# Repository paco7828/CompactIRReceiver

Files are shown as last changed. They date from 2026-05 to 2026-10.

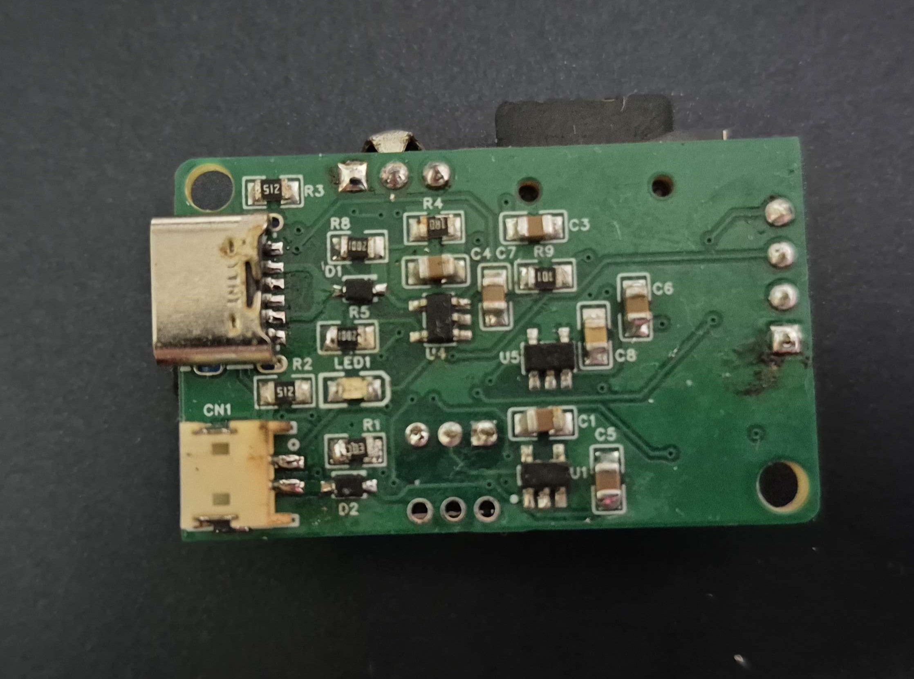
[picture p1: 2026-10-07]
showcase/pcb1.jpg

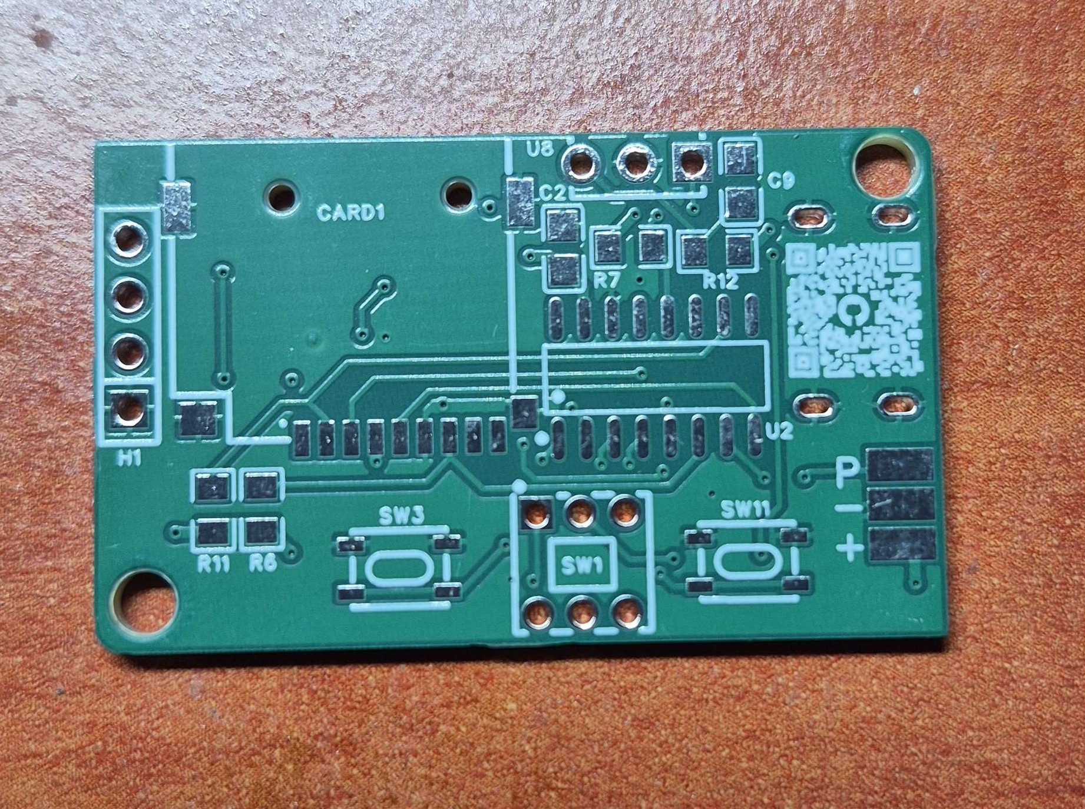
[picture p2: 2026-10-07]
showcase/pcb3.jpg

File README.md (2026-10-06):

# CompactIRReceiver

A palm-sized, battery-powered infrared (IR) signal receiver and logger based on the WCH CH32V003 RISC-V microcontroller. It decodes incoming IR signals, measures raw pulse lengths, displays the output on an I2C OLED display, and optionally logs raw timing data to a FAT32-formatted MicroSD card.

## Technical Specifications

| Component | Specification / Part Number |
| --- | --- |
| Microcontroller | WCH CH32V003A4M6 (RISC-V, 48 MHz, 2 KB RAM, 16 KB Flash) |
| IR Receiver Module | IRM-3638T (38 kHz) |
| Display | 0.91" 128x32 Monochrome I2C OLED (White) |
| Battery & Power | 300 mAh 3.7V LiPo battery |
| Charge Controller | LP4054 (USB-C charging) |
| Battery Protection | XB5352A (Overcharge, over-discharge, overcurrent protection) |
| Voltage Regulator | AP2112K-3.3 LDO (3.3V system power) |
| Power Switch | Latching push button |
| User Interface | 2x Push buttons (Confirm / Cancel) |
| Storage | MicroSD slot (Software SPI mode) |

## System Architecture & Memory Constraints

The CH32V003 has 2 KB of SRAM. To operate within these limits, the firmware shares a single 512-byte buffer (`buf[512]`):
- **UI State:** Used as the monochrome OLED display framebuffer (128x32 / 8 = 512 bytes).

MicroSD communications are handled via a lightweight, bit-banged SPI implementation with custom FAT32 root directory scanning and file writing functions.

## Operating Flow

1. **Boot:** Power on via the latching switch. The OLED displays the splash screen (`IR Receiver`).
2. **Listen:** Press **Confirm** to enter listening mode. The screen displays `Listening` with a loading animation.
   - Pressing **Confirm** or **Cancel** at any time while listening aborts the capture and returns to the boot screen.
3. **Capture:** When a signal is captured, the device displays:
   - Decoded hex value (e.g., `0x12345678`).
   - Total raw pulse count (e.g., `raw length: 32`).
   - Confirm (Check icon) and Cancel (Cross icon) indicators on screen.
4. **Save / Discard:**
   - Press **Confirm** to save the capture to the SD card.
   - Press **Cancel** to discard the capture without writing to disk.
5. **Feedback:** Shows status output (`Saved!`, `No SD card`, `Not FAT32`, `SD wr err`, or `Cancel X`) for 3 seconds before returning to the boot screen.

## SD Card Logging Format

Saved files are stored in the root directory under the 8.3 naming convention: `SIGxxxxx.TXT` (incrementing from `SIG00001.TXT` to `SIG99999.TXT`).

Format inside the text file:
```text
{HEX_VALUE};{RAW_COUNT};{{RAW_PULSE_MICROSECONDS_ARRAY}}
```

Example:
```text
A55A1234;12;{9000,4500,560,1690,560,560,560,1690,560,560,560,560}
```

## Toolchain & Compilation

Built using **MounRiver Studio II** targeting the CH32V003 platform.

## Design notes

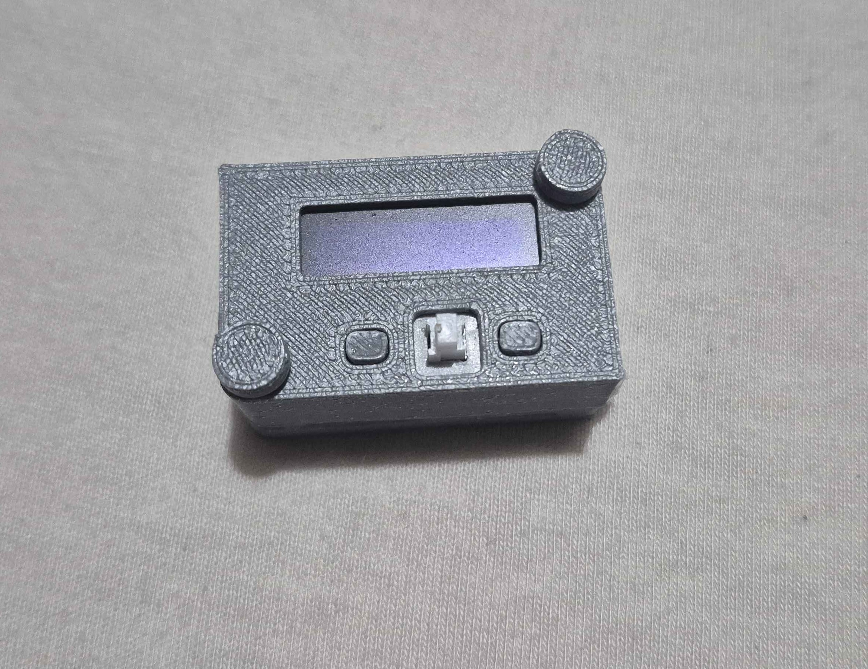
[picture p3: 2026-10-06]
showcase/compactirreceiver1.jpg

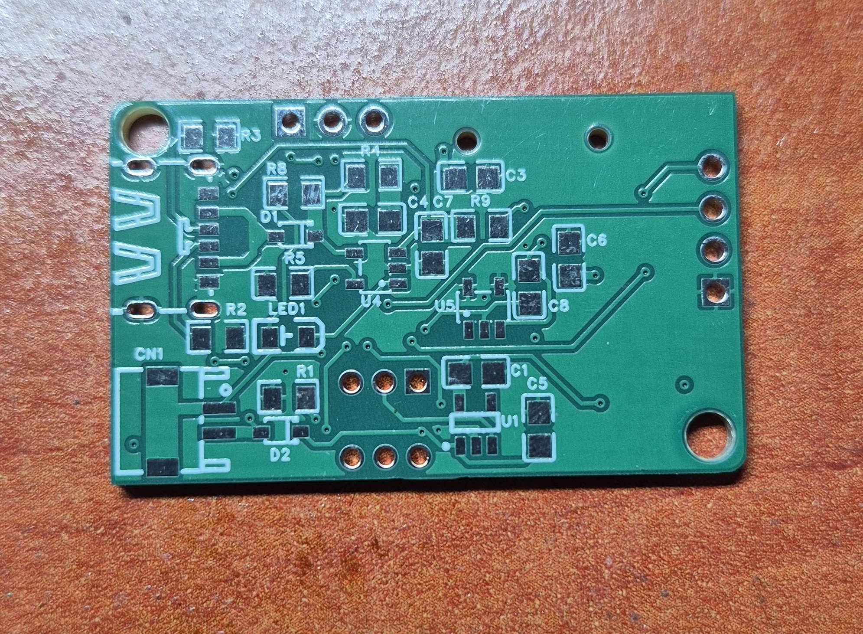
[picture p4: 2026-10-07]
showcase/pcb4.jpg

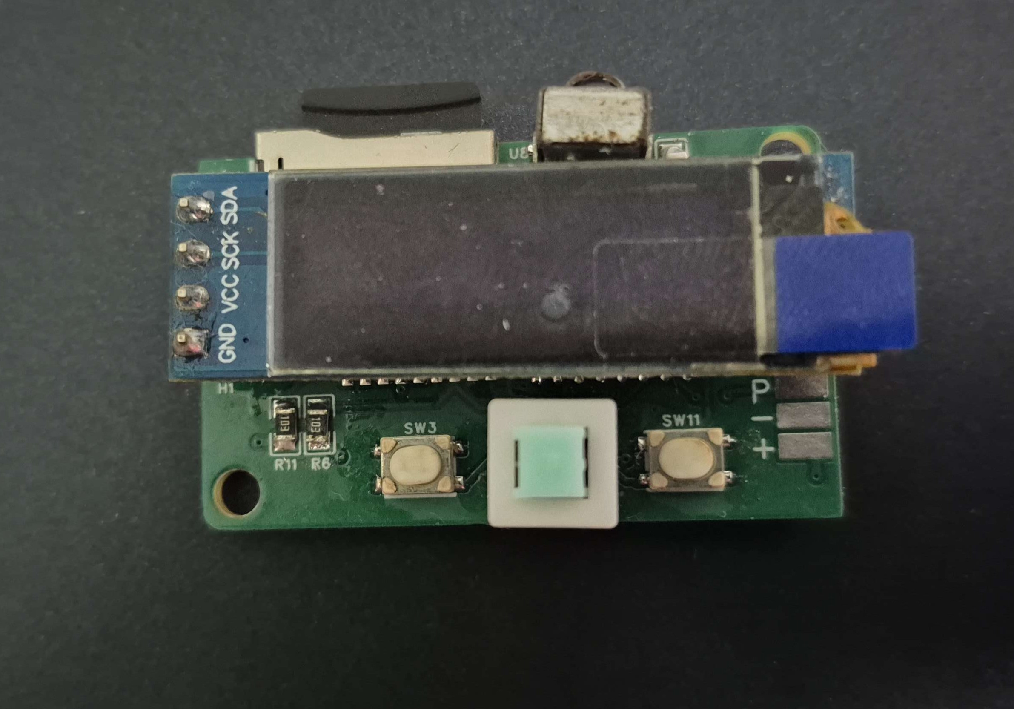
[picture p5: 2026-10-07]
showcase/pcb2.jpg

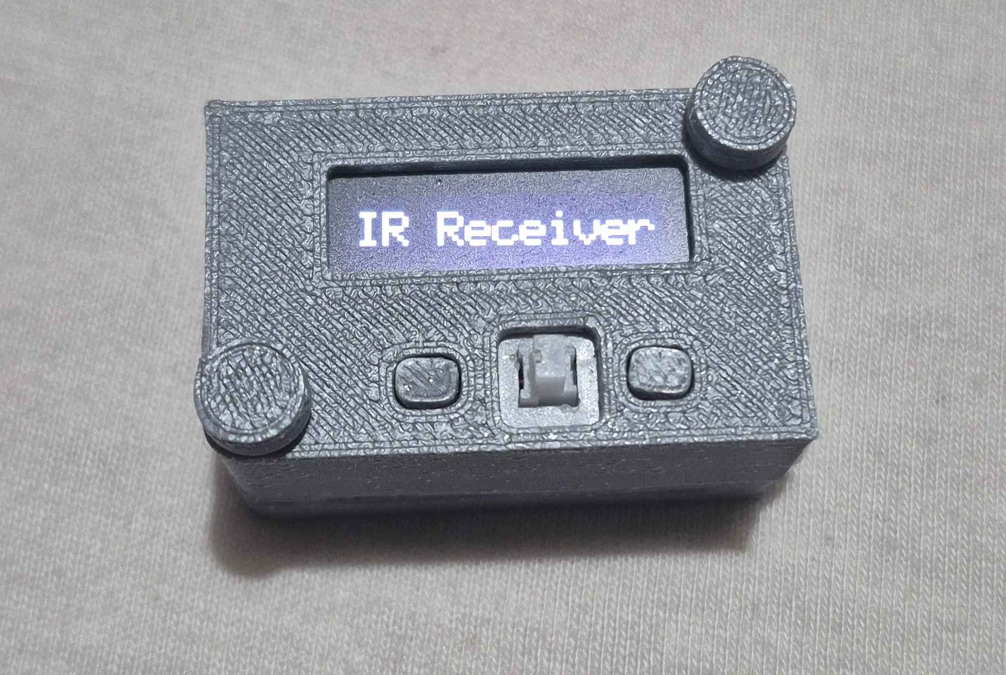
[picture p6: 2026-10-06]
showcase/compactirreceiver2.jpg

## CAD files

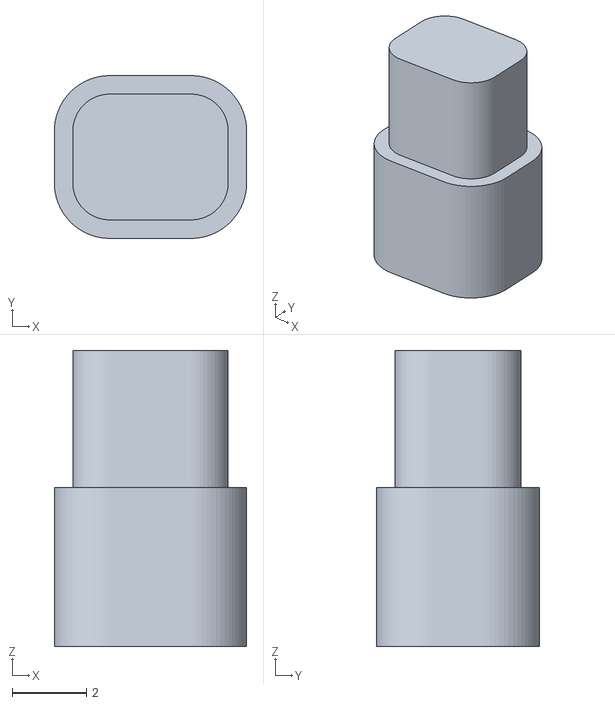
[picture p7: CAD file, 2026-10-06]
3d-files/CompactIRReceiver-button-presser.stl
5.20 x 4.40 x 8.00

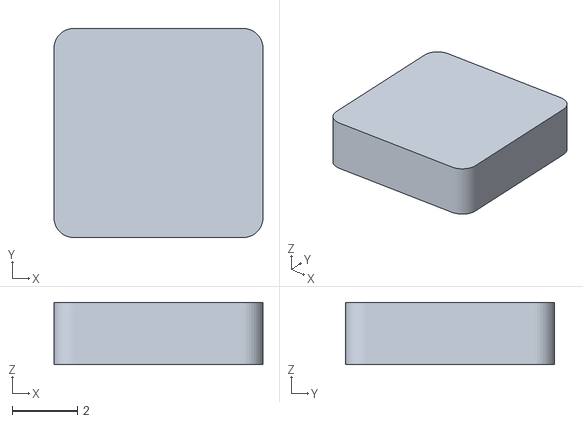
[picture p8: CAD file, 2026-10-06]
3d-files/CompactIRReceiver-power-presser.stl
6.40 x 6.40 x 1.90

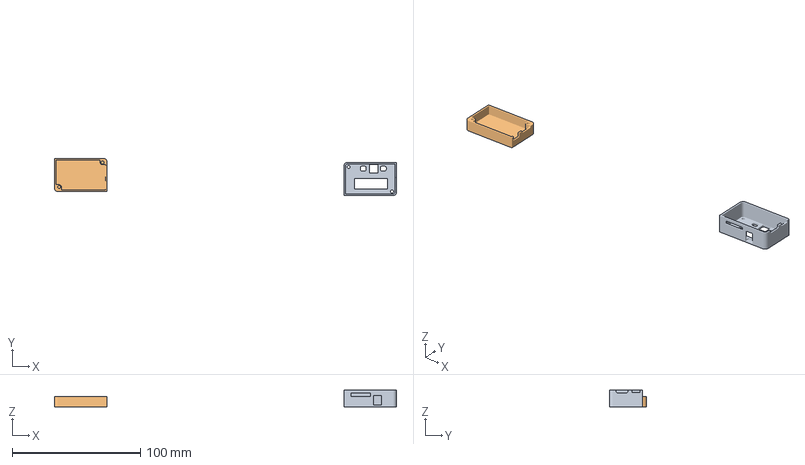
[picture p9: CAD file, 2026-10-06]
3d-files/CompactIRReceiver-box.3mf
266.2 x 29.2 x 13.0 mm
Body1.stl_A
Body1.stl_B

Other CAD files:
3d-files/CompactIRReceiver-box.stl

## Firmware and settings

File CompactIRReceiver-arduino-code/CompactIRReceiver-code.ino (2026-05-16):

#include <IRrecv.h>
#include <IRutils.h>
#include <Wire.h>
#include <Adafruit_GFX.h>
#include <Adafruit_SSD1306.h>
#include <SPI.h>
#include <SD.h>

// Buttons
struct Button {
  int pin;
  int lastReading;
  int stableState;
  unsigned long lastChangeTime;
};
Button btnA = { 1, HIGH, HIGH, 0 };
Button btnB = { 2, HIGH, HIGH, 0 };
const uint8_t DEBOUNCE_DELAY = 50;

// Display
const uint8_t I2C_SDA = 8;
const uint8_t I2C_SCL = 9;
const uint8_t I2C_DISPLAY_ADDR = 0x3C;
const uint8_t SCREEN_WIDTH = 128;
const uint8_t SCREEN_HEIGHT = 32;
const uint8_t OLED_RESET = -1;
const char *MENU_TITLE = "IR logger";

// SD Card
const uint8_t SD_CS = 3;
const uint8_t SD_MOSI = 4;
const uint8_t SD_MISO = 10;
const uint8_t SD_SCK = 7;
const char *NO_SD_FEEDBACK = "No SD card";
bool sdAvailable = false;

// IR signal
const uint8_t IR_PIN = 0;
const int BUF_SIZE = 1024;
const uint8_t IR_TIMEOUT = 15;
const uint8_t MIN_UNKNOWN = 12;

uint64_t capturedValue = 0;
uint16_t capturedRawLen = 0;
uint8_t capturedBytes = 0;
uint8_t signalCount = 0;

// Animation
uint8_t dotCount = 0;
uint8_t dotDirection = 1;
unsigned long lastDotTime = 0;
unsigned long feedbackTime = 0;
const int DOT_INTERVAL = 450;
const int FEEDBACK_DURATION = 1500;

// Modes
const uint8_t MODE_MENU = 0;
const uint8_t MODE_LISTENING = 1;
const uint8_t MODE_CAPTURED = 2;
const uint8_t MODE_SAVED = 3;
const uint8_t MODE_DISCARDED = 4;
uint8_t currentMode = 0;

// Instances
Adafruit_SSD1306 display(SCREEN_WIDTH, SCREEN_HEIGHT, &Wire, OLED_RESET);
IRrecv irrecv(IR_PIN, BUF_SIZE, IR_TIMEOUT, true);
decode_results results;

// Function prorotypes
bool debounceBtn(Button &btn);
void showMenu();
void showListening(uint8_t dots);
void showCaptured();
void drawCheck(uint8_t x, uint8_t y, uint8_t size);
void drawCross(uint8_t x, uint8_t y, uint8_t size);
void showFeedback(bool saved);
int getNextFileIndex();
void displaySDError();
bool saveToSD(int idx);

void setup() {
  Serial.begin(115200);

  // Display I2C
  Wire.begin(I2C_SDA, I2C_SCL);
  if (!display.begin(SSD1306_SWITCHCAPVCC, I2C_DISPLAY_ADDR)) {
    while (1)
      ;
  }

  // SD SPI
  SPI.begin(SD_SCK, SD_MISO, SD_MOSI, SD_CS);
  sdAvailable = SD.begin(SD_CS);
  if (!sdAvailable) {
    displaySDError();
    delay(1500);
  }

  showMenu();
  irrecv.setUnknownThreshold(MIN_UNKNOWN);
  irrecv.enableIRIn();

  pinMode(btnA.pin, INPUT_PULLUP);
  pinMode(btnB.pin, INPUT_PULLUP);
}

// LOOP
void loop() {
  bool pressA = debounceBtn(btnA);
  bool pressB = debounceBtn(btnB);

  switch (currentMode) {

    case MODE_MENU:
      if (pressA) {
        dotCount = 0;
        dotDirection = 1;
        lastDotTime = millis();
        currentMode = MODE_LISTENING;
        irrecv.resume();
        showListening(dotCount);
      }
      break;

    case MODE_LISTENING:

      if (pressA || pressB) {
        currentMode = MODE_MENU;
        showMenu();
        break;
      }

      if (millis() - lastDotTime >= DOT_INTERVAL) {

        dotCount += dotDirection;

        if (dotCount >= 3) {
          dotCount = 3;
          dotDirection = -1;
        } else if (dotCount <= 0) {
          dotCount = 0;
          dotDirection = 1;
        }

        lastDotTime = millis();
        showListening(dotCount);
      }

      if (irrecv.decode(&results)) {
        if (results.decode_type != UNKNOWN && !results.repeat) {
          capturedValue = results.value;
          capturedBytes = (results.bits + 7) / 8;
          capturedRawLen = results.rawlen;
          currentMode = MODE_CAPTURED;
          showCaptured();
        } else {
          irrecv.resume();
        }
      }
      break;

    case MODE_CAPTURED:
      if (pressA || pressB) {
        // SD card OK & Button A pressed
        if (sdAvailable && pressA) {
          // Save signal on SD card
          signalCount++;
          int idx = getNextFileIndex();
          saveToSD(idx);
          feedbackTime = millis();
          currentMode = MODE_SAVED;
          showFeedback(true);
        } else {
          // SD card FAIL (only discard is available)
          feedbackTime = millis();
          currentMode = MODE_DISCARDED;
          showFeedback(false);
        }
      }
      break;

    case MODE_SAVED:
    case MODE_DISCARDED:
      if (millis() - feedbackTime >= FEEDBACK_DURATION) {
        currentMode = MODE_MENU;
        showMenu();
      }
      break;
  }

  delay(10);
}

void displaySDError() {
  display.clearDisplay();
  display.setTextSize(2);
  display.setTextColor(SSD1306_WHITE);
  int16_t x1, y1;
  uint16_t w, h;
  display.getTextBounds(NO_SD_FEEDBACK, 0, 0, &x1, &y1, &w, &h);
  display.setCursor((SCREEN_WIDTH - w) / 2, (SCREEN_HEIGHT - h) / 2);
  display.print(NO_SD_FEEDBACK);
  display.display();
}

bool saveToSD(int idx) {
  char filename[32];
  snprintf(filename, sizeof(filename), "/Signal-%d.txt", idx);

  File file = SD.open(filename, FILE_WRITE);
  if (!file) return false;

  // HEX
  file.print(capturedValue, HEX);
  file.print(";");

  // Raw length
  file.print(capturedRawLen);
  file.print(";{");

  for (int i = 1; i < capturedRawLen; i++) {

    uint32_t val = results.rawbuf[i];

    file.print(val);

    if (i < capturedRawLen - 1) {
      file.print(",");
    }
  }

  file.println("}");
  file.close();
  return true;
}

int getNextFileIndex() {
  int i = 1;
  char path[32];

  while (true) {
    snprintf(path, sizeof(path), "/Signal-%d.txt", i);
    if (!SD.exists(path)) return i;
    i++;
  }
}

// debounce
bool debounceBtn(Button &btn) {
  int reading = digitalRead(btn.pin);

  if (reading != btn.lastReading) {
    btn.lastChangeTime = millis();
  }

  btn.lastReading = reading;

  if (millis() - btn.lastChangeTime > DEBOUNCE_DELAY) {
    if (btn.stableState != reading) {
      btn.stableState = reading;
      if (btn.stableState == LOW) return true;
    }
  }

  return false;
}

void showMenu() {
  display.clearDisplay();
  display.setTextSize(2);
  display.setTextColor(SSD1306_WHITE);
  int16_t x1, y1;
  uint16_t w, h;
  display.getTextBounds(MENU_TITLE, 0, 0, &x1, &y1, &w, &h);
  display.setCursor((SCREEN_WIDTH - w) / 2, (SCREEN_HEIGHT - h) / 2);
  display.print(MENU_TITLE);
  display.display();
}

void showListening(uint8_t dots) {
  display.clearDisplay();
  display.setTextSize(1);
  display.setTextColor(SSD1306_WHITE);

  int16_t x1, y1;
  uint16_t w, h;
  display.getTextBounds("Listening", 0, 0, &x1, &y1, &w, &h);
  display.setCursor((SCREEN_WIDTH - w) / 2, 4);
  display.print("Listening");

  // 3 animated dot circles centered
  const uint8_t DOT_R = 3;
  const uint8_t DOT_GAP = 12;
  const uint8_t DOT_Y = 24;
  uint8_t startX = (SCREEN_WIDTH - (2 * DOT_GAP)) / 2;

  for (uint8_t i = 0; i < 3; i++) {
    uint8_t cx = startX + i * DOT_GAP;
    if (i < dots)
      display.fillCircle(cx, DOT_Y, DOT_R, SSD1306_WHITE);
    else
      display.drawCircle(cx, DOT_Y, DOT_R, SSD1306_WHITE);
  }
  display.display();
}

void showCaptured() {
  char hexStr[20];
  snprintf(hexStr, sizeof(hexStr), "0x%0*llX", capturedBytes * 2, capturedValue);

  char lenStr[12];
  snprintf(lenStr, sizeof(lenStr), "Size: %d", capturedRawLen);

  display.clearDisplay();
  display.setTextColor(SSD1306_WHITE);

  int16_t x1, y1;
  uint16_t w, h;

  // Hex value top-centered
  display.setTextSize(2);
  display.getTextBounds(hexStr, 0, 0, &x1, &y1, &w, &h);
  display.setCursor((SCREEN_WIDTH - w) / 2, 0);
  display.print(hexStr);

  // Signal length
  display.setTextSize(1);
  display.getTextBounds(lenStr, 0, 0, &x1, &y1, &w, &h);
  display.setCursor((SCREEN_WIDTH - w) / 2, 18);
  display.print(lenStr);

  // Bottom icons
  const uint8_t ICON_SIZE = 7;
  const uint8_t ICON_Y = 24;

  if (sdAvailable) {
    drawCheck(6, ICON_Y, ICON_SIZE);
  } else {
    drawCross(6, ICON_Y, ICON_SIZE);
  }
  drawCross(SCREEN_WIDTH - ICON_SIZE - 6, ICON_Y, ICON_SIZE);

  display.display();
}

// Draw checkmark
void drawCheck(uint8_t x, uint8_t y, uint8_t size) {
  // Two-pixel thick check mark scaled to size parameter
  uint8_t mx = x + size * 0.35;
  uint8_t my = y + size;
  display.drawLine(x, y + size * 0.6, mx, my, SSD1306_WHITE);
  display.drawLine(mx, my, x + size, y, SSD1306_WHITE);
  display.drawLine(x, y + size * 0.6 + 1, mx, my + 1, SSD1306_WHITE);
  display.drawLine(mx, my + 1, x + size, y + 1, SSD1306_WHITE);
}

// Draw 'X'
void drawCross(uint8_t x, uint8_t y, uint8_t size) {
  display.drawLine(x, y, x + size, y + size, SSD1306_WHITE);
  display.drawLine(x + size, y, x, y + size, SSD1306_WHITE);
  display.drawLine(x + 1, y, x + size + 1, y + size, SSD1306_WHITE);
  display.drawLine(x + size + 1, y, x + 1, y + size, SSD1306_WHITE);
}

// Display feedback message based on parameter
void showFeedback(bool saved) {
  const char *text = saved ? "Saved" : "Cancel";

  display.clearDisplay();
  display.setTextSize(2);
  display.setTextColor(SSD1306_WHITE);

  int16_t x1, y1;
  uint16_t tw, th;

  display.getTextBounds(text, 0, 0, &x1, &y1, &tw, &th);

  const uint8_t ICON_SIZE = 10;
  const uint8_t GAP = 6;

  // Text & icon width
  uint16_t totalW = tw + GAP + ICON_SIZE;

  uint8_t startX = (SCREEN_WIDTH - totalW) / 2;
  uint8_t textY = (SCREEN_HEIGHT - th) / 2;
  uint8_t iconY = textY + 2;

  // Draw text
  display.setCursor(startX, textY);
  display.print(text);

  // Draw icon after text
  uint8_t iconX = startX + tw + GAP;

  if (saved)
    drawCheck(iconX, iconY, ICON_SIZE);
  else
    drawCross(iconX, iconY, ICON_SIZE);

  display.display();
}

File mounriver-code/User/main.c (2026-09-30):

/*
 * CH32V003A4M6 - IR receiver / logger  (MounRiver Studio II)
 * PA1 IRM3638 | PC1 SDA | PC2 SCL | PC3 CONFIRM | PC4 CANCEL
 * PC6 SD CMD | PC7 SD DAT0 | PD4 SD CLK | PD6 SD DAT3(CS) | PD1 SWIO (untouched)
 * buf[512] = OLED framebuffer AND SD sector buffer (shared, RAM is 2 KB)
 */
#include "ch32v00x.h"
#include <string.h>

extern uint32_t SystemCoreClock;

#define RAW_MAX 320
#define MIN_ENTRIES 12
#define IR_GAP_US 15000
#define OLED_ADDR 0x3C
#define DEBOUNCE_MS 40
#define ANIM_MS 400
#define FEEDBACK_MS 3000
#define FAT_DATE 0x5C21

static uint32_t tpms;

static inline uint32_t now (void) { return SysTick->CNT; }

static uint8_t elapsed (uint32_t t0, uint32_t ms) { return (uint32_t)(now() - t0) >= ms * tpms; }

static void delay_ms (uint32_t ms) {
    uint32_t t0 = now();
    while (!elapsed (t0, ms));
}

static void delay_us (uint32_t us) {
    uint32_t t0 = now(), n = us * (tpms / 1000);
    while ((uint32_t)(now() - t0) < n);
}

/* ---------- IR RX ---------- */
static volatile uint16_t raw[RAW_MAX];
static volatile uint16_t rawn, rx_last;
static volatile uint8_t rx_started;

void EXTI7_0_IRQHandler (void) __attribute__ ((interrupt ("WCH-Interrupt-fast")));

void EXTI7_0_IRQHandler (void) {
    uint16_t t = TIM2->CNT;
    uint8_t low = !(GPIOA->INDR & (1u << 1));
    EXTI->INTFR = (1u << 1);
    if (!rx_started) {
        if (low) {
            rx_started = 1;
            rx_last = t;
            rawn = 0;
        }
    } else {
        uint16_t d = t - rx_last;
        rx_last = t;
        if (rawn < RAW_MAX)
            raw[rawn++] = d;
    }
}

static void rx_start (void) {
    rx_started = 0;
    rawn = 0;
    EXTI->INTFR = (1u << 1);
    EXTI->INTENR |= (1u << 1);
}

static void rx_stop (void) { EXTI->INTENR &= ~(1u << 1); }

static uint8_t rx_poll (void) {
    uint16_t l, c;
    if (!rx_started)
        return 0;
    l = rx_last;
    c = TIM2->CNT;
    if ((uint16_t)(c - l) < IR_GAP_US)
        return 0;
    rx_stop();
    if (rawn >= MIN_ENTRIES)
        return 1;
    rx_start();
    return 0;
}

static uint8_t cap_digits;

static uint32_t decode_ir (void) {
    uint16_t n = rawn, s = 0, i, mn[2] = {0xFFFF, 0xFFFF}, mx[2] = {0, 0};
    uint8_t k, nb = 0;
    uint32_t v = 0;

    if (raw[0] > 2000)
        s = 2;
    for (i = s; i < n; i++) {
        uint16_t d = raw[i];
        k = (i - s) & 1;
        if (d < mn[k])
            mn[k] = d;
        if (d > mx[k])
            mx[k] = d;
    }
    if (n > s + 3) {
        if (mx[1] > mn[1] + (mn[1] >> 1))
            k = 1;
        else if (mx[0] > mn[0] + (mn[0] >> 1))
            k = 0;
        else
            k = 2;
        if (k < 2) {
            uint16_t thr = mn[k] + (mn[k] >> 1);
            for (i = s + k; i < n; i += 2) {
                v = (v << 1) | (raw[i] > thr);
                nb++;
            }
            cap_digits = (nb >= 32) ? 8 : 2 * ((nb + 7) >> 3);
            return v;
        }
    }
    {
        uint16_t base = 0xFFFF;
        v = 2166136261u;
        for (i = 0; i < n; i++)
            if (raw[i] < base)
                base = raw[i];
        if (base < 50)
            base = 50;
        for (i = 0; i < n; i++) {
            uint32_t q = ((uint32_t)raw[i] * 2 + base) / (2u * base);
            v = (v ^ q) * 16777619u;
        }
    }
    cap_digits = 8;
    return v;
}

/* ---------- GPIO ---------- */
static void gpio_cfg (GPIO_TypeDef *g, uint8_t pin, uint8_t cfg) {
    g->CFGLR = (g->CFGLR & ~(0xFu << (pin * 4))) | ((uint32_t)cfg << (pin * 4));
}

#define CFG_IPU 0x8
#define CFG_OUT 0x1
#define CFG_AFOD 0xD

/* ---------- OLED (I2C1) ---------- */
static uint8_t buf[512];
#define fb buf

static void i2c_recover (void) {
    uint8_t i;
    I2C1->CTLR1 = 0;                                        /* PE off */
    gpio_cfg (GPIOC, 1, 0x5);
    gpio_cfg (GPIOC, 2, 0x5);                               /* GPIO open-drain */
    GPIOC->BSHR = (1u << 1) | (1u << 2);                    /* release SDA, SCL */
    delay_us (10);
    for (i = 0; i < 9 && !(GPIOC->INDR & (1u << 1)); i++) { /* SDA stuck low */
        GPIOC->BCR = 1u << 2;
        delay_us (10);
        GPIOC->BSHR = 1u << 2;
        delay_us (10);
    }
    GPIOC->BCR = 1u << 1;
    delay_us (10); /* STOP condition */
    GPIOC->BSHR = 1u << 1;
    delay_us (10);
    gpio_cfg (GPIOC, 1, CFG_AFOD);
    gpio_cfg (GPIOC, 2, CFG_AFOD);
    I2C1->CTLR2 = SystemCoreClock / 1000000;
    I2C1->CKCFGR = 0x8000 | (SystemCoreClock / (3 * 400000));
    I2C1->CTLR1 = 1;
}

static uint8_t i2c_wait (uint16_t mask) {
    uint16_t t = 60000;
    while (!(I2C1->STAR1 & mask))
        if (!--t)
            return 0;
    return 1;
}

static uint8_t i2c_begin (void) {
    uint16_t t = 60000;
    while (I2C1->STAR2 & 2)
        if (!--t)
            return 0;
    I2C1->CTLR1 |= (1u << 8);
    if (!i2c_wait (1u << 0))
        goto fail;
    I2C1->DATAR = OLED_ADDR << 1;
    if (!i2c_wait (1u << 1))
        goto fail;
    (void)I2C1->STAR2;
    return 1;
fail:
    I2C1->CTLR1 |= (1u << 9);
    return 0;
}

static void i2c_tx (uint8_t d) {
    if (i2c_wait (1u << 7))
        I2C1->DATAR = d;
}

static void i2c_stop (void) {
    i2c_wait (1u << 2);
    I2C1->CTLR1 |= (1u << 9);
}

static uint8_t oled_cmds (const uint8_t *c, uint8_t n) {
    if (!i2c_begin()) {
        i2c_recover();
        return 0;
    }
    i2c_tx (0x00);
    while (n--) i2c_tx (*c++);
    i2c_stop();
    return 1;
}

static void oled_init (void) {
    static const uint8_t init[] = {
        0xAE, 0xD5, 0x80, 0xA8, 0x1F, 0xD3, 0x00, 0x40, 0x8D, 0x14, 0x20, 0x00,
        0xA1, 0xC8, 0xDA, 0x02, 0x81, 0x8F, 0xD9, 0xF1, 0xDB, 0x40, 0xA4, 0xA6, 0xAF};
    uint8_t i;
    for (i = 0; i < 5; i++) {
        i2c_recover();
        if (oled_cmds (init, sizeof (init)))
            break;
        delay_ms (50);
    }
    delay_ms (10);
    oled_cmds (init, sizeof (init)); /* second pass: harmless, catches a late reset release */
}

static void oled_flush (void) {
    static const uint8_t win[] = {0x21, 0, 127, 0x22, 0, 3};
    uint16_t i;
    oled_cmds (win, sizeof (win));
    if (!i2c_begin())
        return;
    i2c_tx (0x40);
    for (i = 0; i < 512; i++) i2c_tx (fb[i]);
    i2c_stop();
}
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

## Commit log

2026-06-03 Added proto pcb images.
2026-06-18 Added v2 PCB files.
2026-10-06 Added final device showcase videos/images and a README file.
2026-10-06 Reorganized and added .stl files.
    [CompactIRReceiver-box.3mf, CompactIRReceiver-box.stl, CompactIRReceiver-button-presser.stl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]
2026-10-07 Added pcb images to showcase.
